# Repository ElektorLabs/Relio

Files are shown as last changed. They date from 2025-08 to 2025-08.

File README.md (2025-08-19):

# Relio
Relio : A Matter-Enabled Smart Controller for AC Appliances 
**Version:** v1  

## 📖 Project Overview

This project is a **Matter-enabled smart controller** built around the ESP32, with support for **relay control, environment sensing, energy monitoring, and occupancy detection**.  
It combines **hardware (KiCAD PCB design)** and **firmware (Arduino/C++ code)** into a single, ready-to-build system.

---

## 📂 Repository Structure

```

├── hardware/      # KiCAD PCB design files (schematics & layout)
└── src/           # Source code (Arduino / ESP-IDF compatible)

````

---

## ⚙️ Features

- **3x On/Off Lights** 💡  
  Controlled through a TCA9554 I²C expander.  
  - Always start **OFF** when powered up (safe startup).  
  - Exposed as **separate Matter endpoints**.  

- **Environmental Sensing (BME688)** 🌡️💧  
  - Temperature & Humidity exposed to Matter.  
  - Pressure & Gas Resistance logged to Serial for debugging.  

- **Energy Monitoring (BL0942)** ⚡  
  - Measures Voltage, Current, Power, Energy, Frequency.  
  - Data shown in Serial logs (Watts/Current can later be exposed to Matter).  

- **Occupancy Detection** 🚶‍♂️  
  - Uses TCA9554 pin 0 as input.  
  - HIGH = Occupied, LOW = Not Occupied.  
  - Reflected in Matter occupancy endpoint.  

- **Commissioning & Control** 🔐  
  - Commission into Matter fabric with QR/Manual code.  
  - BOOT button short press = toggle Light 1.  
  - BOOT button long press (5s) = decommission node.  

---

## 🧑‍💻 How the Code Works

- **Relay Control:**  
  `SWITCH1/2/3` booleans track relay states. Callbacks ensure Matter state and hardware (TCA9554 relays) stay in sync.  

- **BME688:**  
  Reads real temperature/humidity every 5s → updates Matter.  
  Pressure/gas logged for debugging but not exposed to Matter (yet).  

- **BL0942:**  
  Runs on `Serial1` (pins RX=4, TX=5, 4800 baud). Provides live power metrics to Serial monitor.  

- **Occupancy:**  
  Directly read from **TCA9554 pin 0**. When state changes, it’s pushed to the Matter controller and printed to Serial.  

---

## 🚀 Getting Started

1. Clone this repo:  
   ```bash
   git clone https://github.com/ElektorLabs/Relio.git
2. Open the src/ folder in Arduino IDE or PlatformIO.

3. Install dependencies:

   * [Espressif Matter Arduino](https://github.com/espressif/arduino-esp32)
   * [TCA9554 library](https://github.com/RobTillaart/TCA9554)
   * [BL0942 library](https://github.com/santerilindfors/BL0942)
   * [BME688 library](https://github.com/styropyr0/BME688)

4. Upload the code to your ESP32.

5. Use your Matter controller app to commission the device.

## 🛠️ Future Work

* Expose BL0942 **Power/Current** as native Matter attributes.
* Add Matter endpoints for **Pressure** & **Gas Resistance**.
* Add **configurable boot behavior** (restore last state vs always OFF).

---

## ⚠️ Disclaimer

This project is provided **as-is**, without warranty of any kind.
⚡ **Caution:** This project involves **mains-level voltages** (relays, energy metering).
Only experienced users should build or test this hardware. Always follow **electrical safety best practices** when working with AC-powered circuits.

The author is **not responsible** for any damage, injury, or loss caused by misuse of this code or hardware.

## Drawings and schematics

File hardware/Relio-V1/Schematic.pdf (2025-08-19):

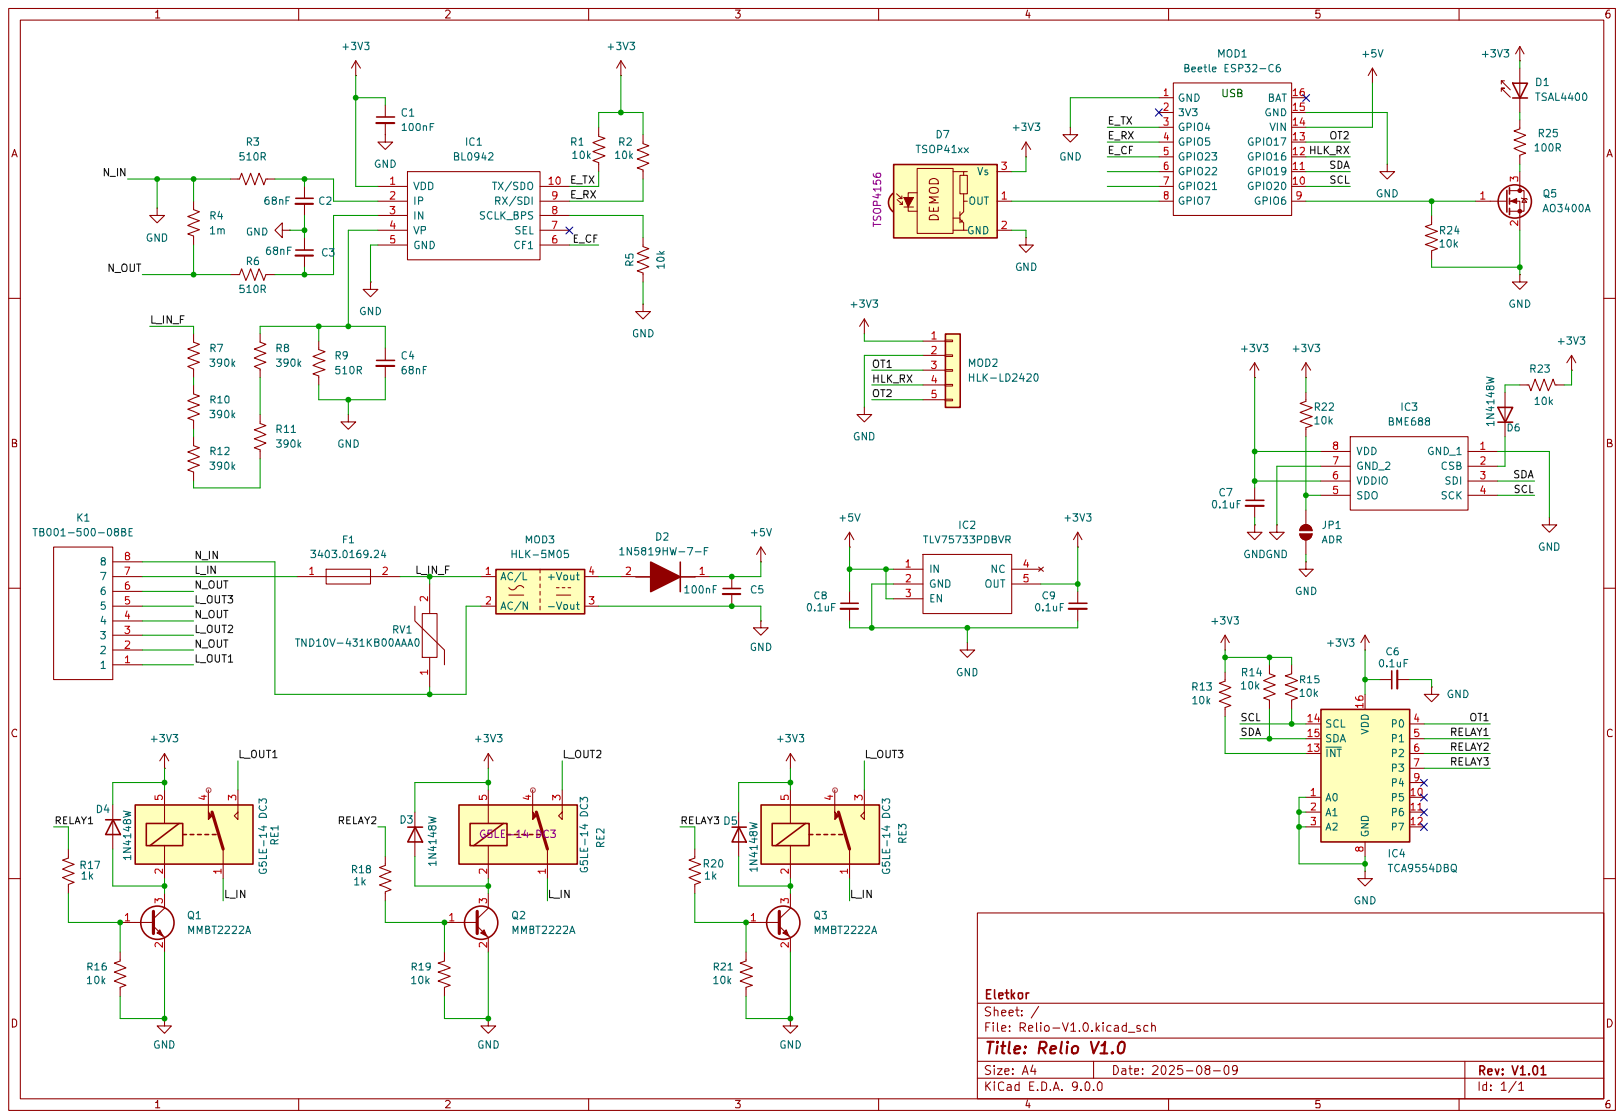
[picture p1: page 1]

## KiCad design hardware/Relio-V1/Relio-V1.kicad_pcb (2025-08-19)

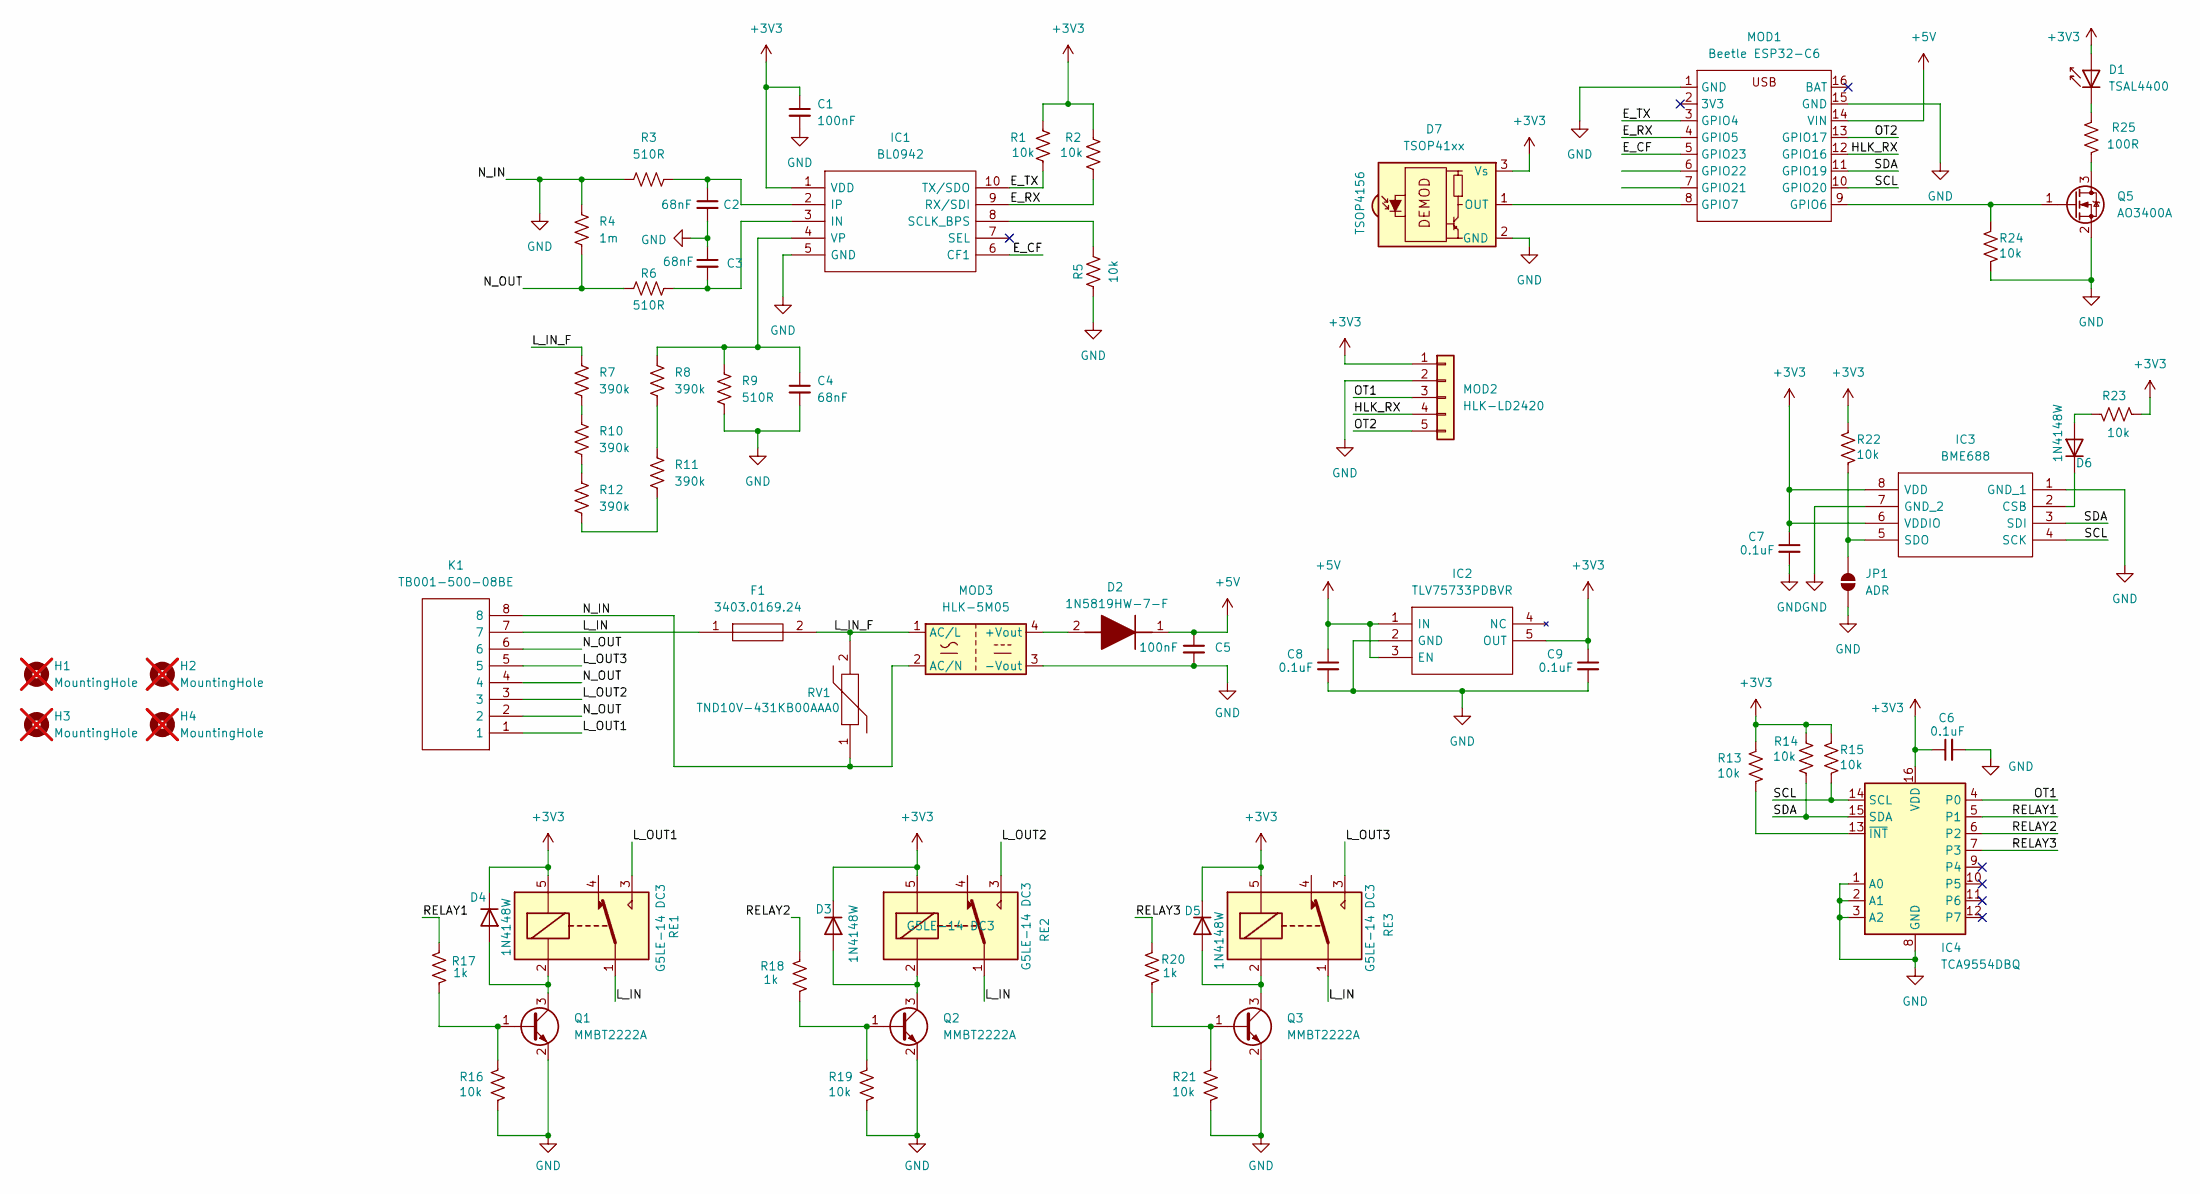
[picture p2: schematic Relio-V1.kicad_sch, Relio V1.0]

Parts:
C1, C5: 100nF; C_0805_2012Metric_Pad1.18x1.45mm_HandSolder; Manufacturer_Part_Number C0805C104M3RAC
C2, C3, C4: 68nF; C_0805_2012Metric_Pad1.18x1.45mm_HandSolder; Manufacturer_Part_Number C0805C683KARACAUTO
C6, C7, C8, C9: 0.1uF; C_0805_2012Metric_Pad1.18x1.45mm_HandSolder; Manufacturer_Part_Number C0805C104M3RAC
D1: TSAL4400; LED_D3.0mm_IRBlack; Manufacturer_Part_Number TSAL4400
D2: 1N5819HW-7-F; SOD3716X145N; Mouser Part Number 621-1N5819HW-F
D3, D4, D5, D6: 1N4148W; D_SOD-123; Manufacturer_Part_Number 1N4148W
D7: TSOP41xx; Vishay_MINICAST-3Pin; Manufacturer_Part_Number TSOP4156
F1: 3403.0169.24; FUSC10130X300N; Mouser Part Number 693-3403.0169.24
H1, H2, H3, H4: MountingHole; MountingHole_3.2mm_M3; not fitted
IC1: BL0942; SOP50P490X110-10N; Manufacturer_Part_Number BL0942
IC2: TLV75733PDBVR; SOT95P280X145-5N; Mouser Part Number 595-TLV75733PDBVR
IC3: BME688; Mouser Part Number 262-BME688
IC4: TCA9554DBQ; SSOP-16_3.9x4.9mm_P0.635mm; Manufacturer_Part_Number TCA9554DBQ
JP1: ADR; SolderJumper-2_P1.3mm_Open_RoundedPad1.0x1.5mm
K1: TB001-500-08BE; TB00150008BE; Mouser Part Number 490-TB001-500-08BE
MOD1: Beetle ESP32-C6; Manufacturer_Part_Number Beetle ESP32-C6
MOD2: HLK-LD2420; PinHeader_1x05_P2.54mm_Vertical; Manufacturer_Part_Number HLK-LD2420
MOD3: HLK-5M05; Converter_ACDC_Hi-Link_HLK-5Mxx; Manufacturer_Part_Number HLK-5M05
Q1, Q2, Q3: MMBT2222A; SOT-23; Manufacturer_Part_Number MMBT2222A
Q5: AO3400A; SOT-23; Manufacturer_Part_Number AO3400A
R1, R2, R5, R13, R14, R15, R16, R19, R21, R22, R23, R24: 10k; R_0805_2012Metric_Pad1.20x1.40mm_HandSolder; Manufacturer_Part_Number 0805W8J0103T5E
R3, R6, R9: 510R; R_0805_2012Metric_Pad1.20x1.40mm_HandSolder; Manufacturer_Part_Number SDR10EZPF5100
R4: 1m; R_1210_3225Metric
R7, R8, R10, R11, R12: 390k; R_2010_5025Metric; Manufacturer_Part_Number CRGCQ2010F390K
R17, R18, R20: 1k; R_0805_2012Metric_Pad1.20x1.40mm_HandSolder; Manufacturer_Part_Number 0805W8J0102T5E
R25: 100R; R_0805_2012Metric_Pad1.20x1.40mm_HandSolder; Manufacturer_Part_Number 0805S8J0101T5E
RE1, RE2, RE3: G5LE-14 DC3; Relay_SPDT_Omron-G5LE-1; Manufacturer_Part_Number G5LE-14 DC3
RV1: TND10V-431KB00AAA0; TND10V431KB00AAA0; Manufacturer_Part_Number TND10V-431KB00AAA0

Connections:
+3V3: C1.1, C6.1, C7.1, C9.1, D1.2 (A), D3.1 (K), D4.1 (K), D5.1 (K), D7.3 (Vs), IC1.1 (VDD), IC2.5 (OUT), IC3.6 (VDDIO), IC3.8 (VDD), IC4.16 (VDD), MOD2.1, R1.1, R2.1, R13.1, R14.1, R15.1, R22.1, R23.1, RE1.5, RE2.5, RE3.5
+5V: C5.1, C8.1, D2.1 (K), IC2.1 (IN), IC2.3 (EN), MOD1.14 (VIN)
/E_CF: IC1.6 (CF1), MOD1.5 (GPIO23)
/E_RX: IC1.9 (RX/SDI), MOD1.4 (GPIO5), R2.2
/E_TX: IC1.10 (TX/SDO), MOD1.3 (GPIO4), R1.2
/HLK_RX: MOD1.12 (GPIO16), MOD2.4
/L_IN: F1.1, K1.7, RE1.1, RE2.1, RE3.1
/L_IN_F: F1.2, MOD3.1 (AC/L), R7.2, RV1.2
/L_OUT1: K1.1, RE1.3
/L_OUT2: K1.3, RE2.3
/L_OUT3: K1.5, RE3.3
/N_OUT: K1.2, K1.4, K1.6, R4.1, R6.1
/OT1: IC4.4 (P0), MOD2.3
/OT2: MOD1.13 (GPIO17), MOD2.5
/RELAY1: IC4.5 (P1), R17.2
/RELAY2: IC4.6 (P2), R18.2
/RELAY3: IC4.7 (P3), R20.2
/SCL: IC3.4 (SCK), IC4.14 (SCL), MOD1.10 (GPIO20), R15.2
/SDA: IC3.3 (SDI), IC4.15 (SDA), MOD1.11 (GPIO19), R14.2
GND: C1.2, C2.2, C3.1, C4.2, C5.2, C6.2, C7.2, C8.2, C9.2, D7.2 (GND), IC1.5 (GND), IC2.2 (GND), IC3.1 (GND_1), IC3.7 (GND_2), IC4.1 (A0), IC4.2 (A1), IC4.3 (A2), IC4.8 (GND), JP1.1 (A), K1.8, MOD1.1 (GND), MOD1.15 (GND), MOD2.2, MOD3.2 (AC/N), MOD3.3 (-Vout), Q1.2 (E), Q2.2 (E), Q3.2 (E), Q5.2 (S), R3.1, R4.2, R5.1, R9.1, R16.2, R19.2, R21.2, R24.2, RV1.1
unnamed: D1.1 (K), R25.1
unnamed: D2.2 (A), MOD3.4 (+Vout)
unnamed: D3.2 (A), Q2.3 (C), RE2.2
unnamed: D4.2 (A), Q1.3 (C), RE1.2
unnamed: D5.2 (A), Q3.3 (C), RE3.2
unnamed: D6.2 (A), R23.2
unnamed: D6.1 (K), IC3.2 (CSB)
unnamed: D7.1 (OUT), MOD1.8 (GPIO7)
unnamed: C3.2, IC1.3 (IN), R6.2
unnamed: C2.1, IC1.2 (IP), R3.2
unnamed: IC1.8 (SCLK_BPS), R5.2
unnamed: C4.1, IC1.4 (VP), R8.2, R9.2
unnamed: IC3.5 (SDO), JP1.2 (B), R22.2
unnamed: IC4.13 (~INT), R13.2
unnamed: MOD1.9 (GPIO6), Q5.1 (G), R24.1
unnamed: Q1.1 (B), R16.1, R17.1
unnamed: Q2.1 (B), R18.1, R19.1
unnamed: Q3.1 (B), R20.1, R21.1
unnamed: Q5.3 (D), R25.2
unnamed: R10.1, R12.1
unnamed: R7.1, R10.2
unnamed: R11.1, R12.2
unnamed: R8.1, R11.2

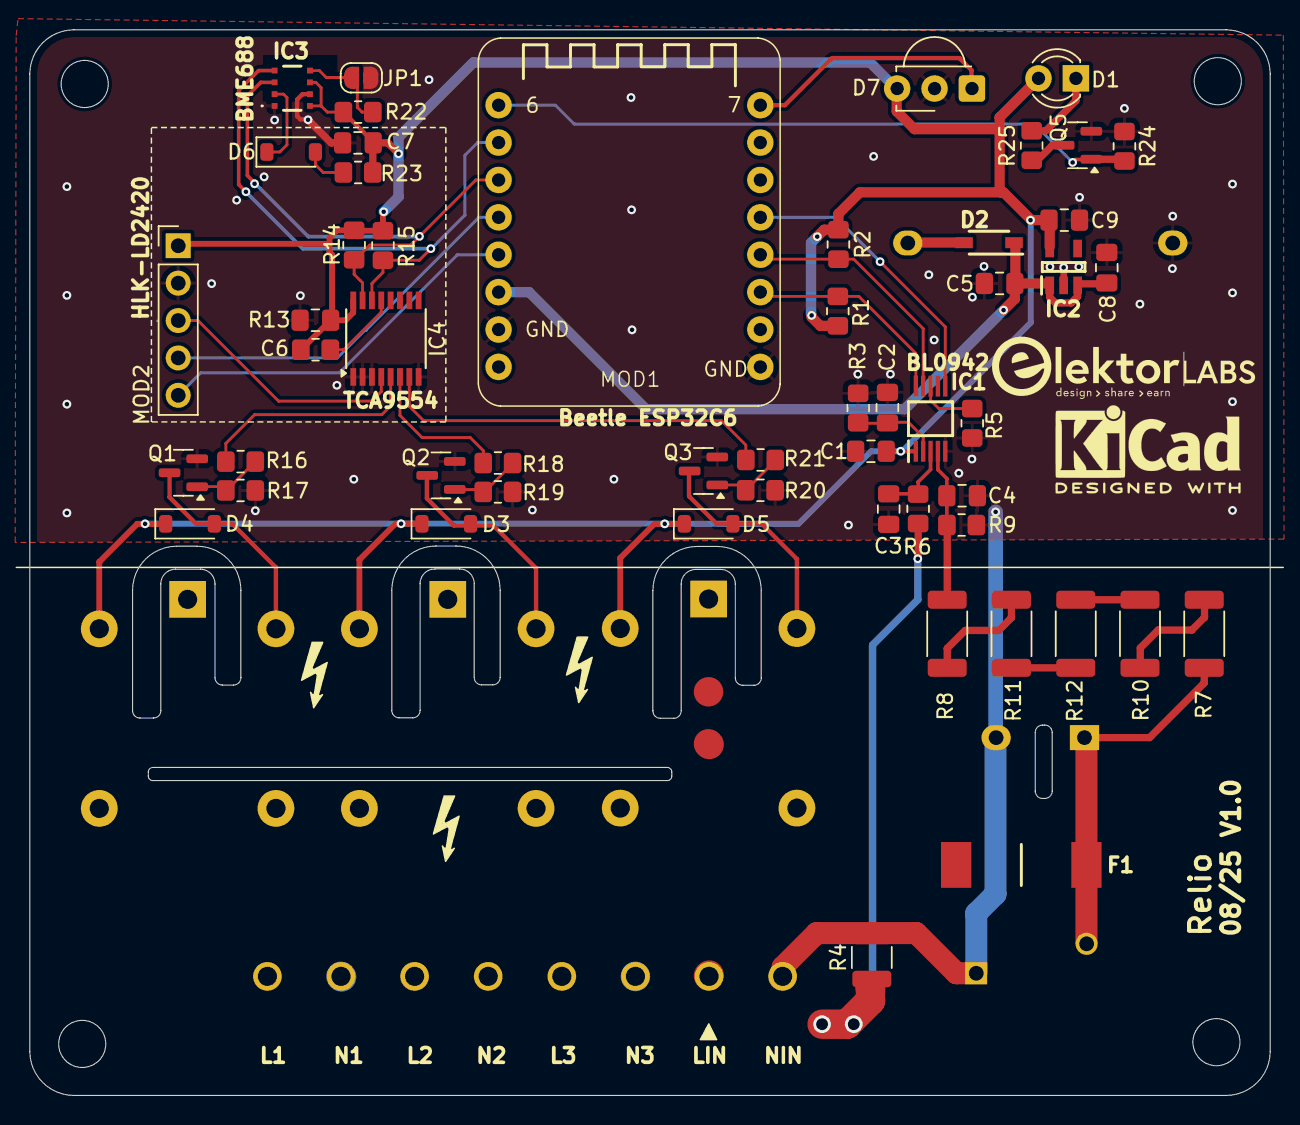
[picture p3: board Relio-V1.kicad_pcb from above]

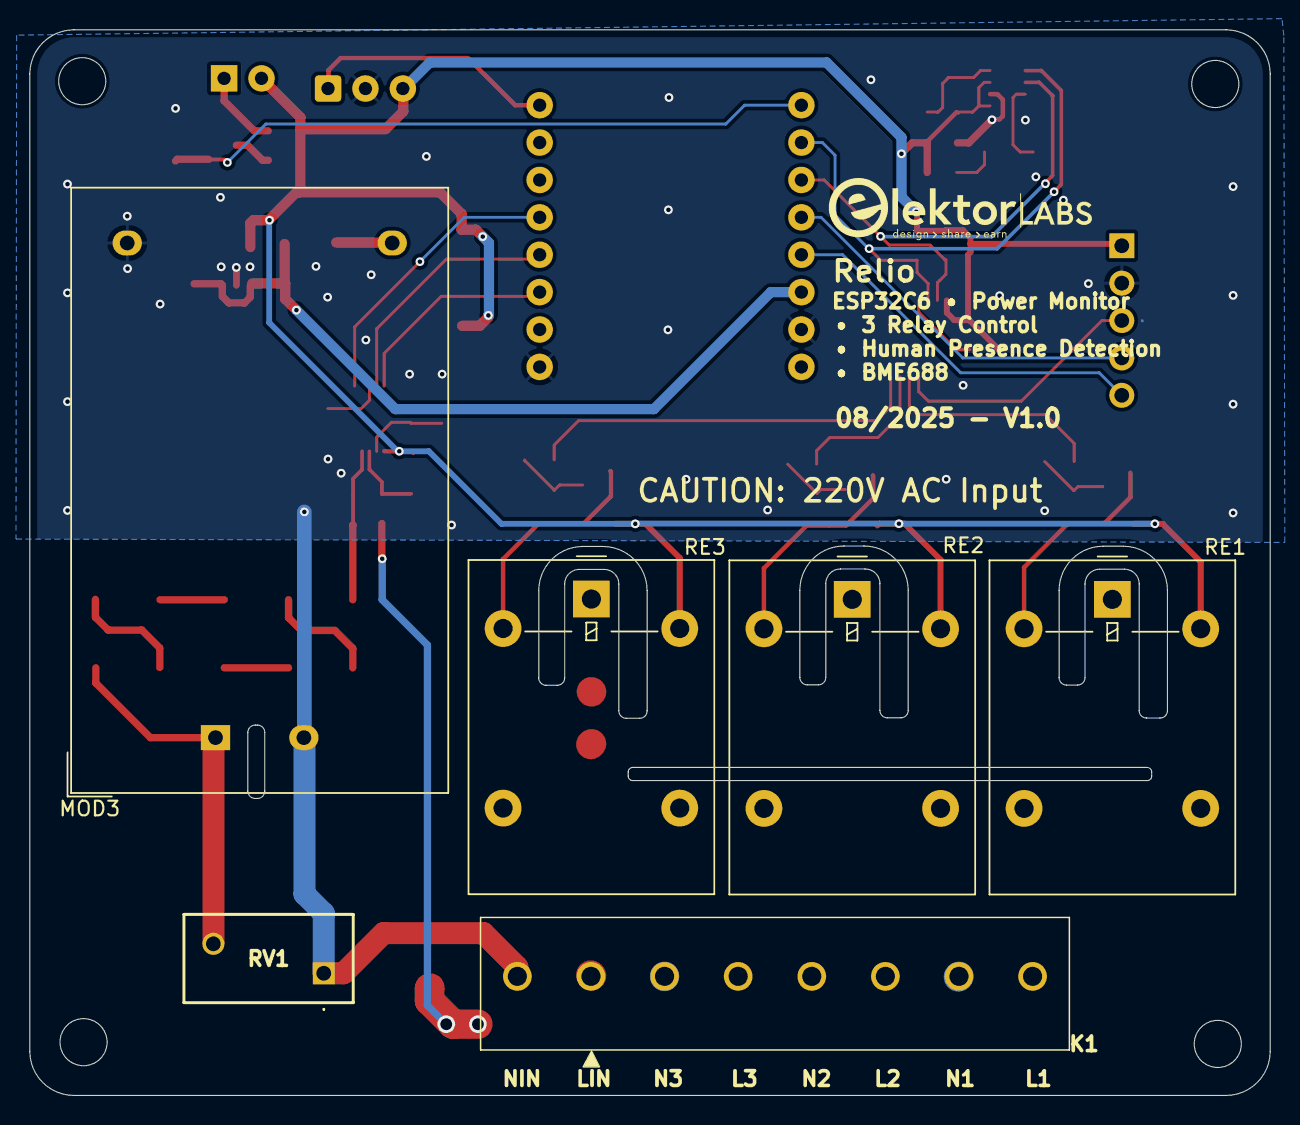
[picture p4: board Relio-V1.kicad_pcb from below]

Board: 2 copper layers, 84.3 x 72.4 mm, 63 parts (6 on the bottom side), 43 nets.

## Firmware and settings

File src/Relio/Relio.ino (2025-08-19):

/*
  Project: Relio : Multi-Endpoint Matter Device with Environmental & Energy Monitoring
  Version: v1
  Author : Saad Imtiaz
  Date   : 16 August 2025

  ---------------------------------------------------------------------------
  Functionality:
  - Implements a Matter node with multiple endpoints:
      • 3x On/Off switches mapped to relays via TCA9554 I²C expander
        → always forced OFF at startup (hardware + Matter state)
      • Temperature & Humidity via BME688 (I²C @ 0x76)
        → real sensor data exposed to Matter, pressure & gas printed to Serial
      • Occupancy sensor controlled by a boolean variable (OCCUPANCY)
      • Energy monitoring via BL0942 (UART on pins RX=4, TX=5)
        → Voltage, Current, Power, Energy, Frequency printed to Serial
  - Supports commissioning / decommissioning into a Matter fabric
    • Short press on BOOT button toggles Light 1
    • Long press (5s) decommissions the node

  ---------------------------------------------------------------------------
  Features Implemented:
  ✔ 3x Relay control with Matter synchronization
  ✔ Safe startup (all relays OFF, state reflected in controller)
  ✔ Real-time Temperature & Humidity from BME688
  ✔ Pressure & Gas resistance (BME688) logged to Serial
  ✔ Occupancy endpoint.
  ✔ BL0942 energy meter integration (Serial monitoring)
  ✔ Commissioning status & QR/manual pairing codes over Serial

  ---------------------------------------------------------------------------
  Features To Be Added (future roadmap):
  - Expose BL0942 power/current data as official Matter endpoint(s)
  - Add optional Matter endpoint for BME688 Pressure & Gas Resistance
  - User-configurable boot policy (restore last state vs always-off)
  - Error handling / fallback if BME688 or BL0942 not detected
    ---------------------------------------------------------------------------
*/

#include <Matter.h>
#if !CONFIG_ENABLE_CHIPOBLE
#include <WiFi.h>
#endif
#include <Preferences.h>
#include <Wire.h>
#include "TCA9554.h"
#include <BME688.h>


// ====== BL0942 Energy Meter ======
#include <BL0942.h>
#define BL0942_RX 4
#define BL0942_TX 5
bl0942::BL0942 blSensor(Serial1);

// === Compile-time option: expose Watts (or Current) in Matter ===
// Set to 1 to enable, and make sure your SDK provides a suitable endpoint.
// Common names you might have in recent Arduino Matter builds include something like
// MatterElectricalMeasurement / MatterPowerMeter / MatterPowerSensor.
//
// If you enable, adjust the include/class/methods in the MARKED SECTION below.
#define EXPOSE_WATTS_IN_MATTER 0   // 0 = Serial only (safe default), 1 = publish to Matter (needs endpoint support)
#define PUBLISH_WATTS           1   // 1 = publish watts, 0 = publish current (amps) if endpoint supports it


// WiFi credentials if not using CHIP over BLE
#if !CONFIG_ENABLE_CHIPOBLE
const char *ssid = "xxx";
const char *password = "xxx";
#endif


// ---------- Matter Endpoints ----------
MatterOnOffLight        OnOffLight1;
MatterOnOffLight        OnOffLight2;
MatterOnOffLight        OnOffLight3;
MatterTemperatureSensor TempSensor;
MatterHumiditySensor    HumSensor;
MatterOccupancySensor   Occupancy;
// ---------- Logical states ----------
bool SWITCH1 = false;
bool SWITCH2 = false;
bool SWITCH3 = false;
bool OCCUPANCY = false;  // set true/false in your app logic

// ---------- Persistence ----------
Preferences matterPref;
static constexpr const char *kNS        = "MatterPrefs";
static constexpr const char *kOnOffKey1 = "OnOff1";
static constexpr const char *kOnOffKey2 = "OnOff2";
static constexpr const char *kOnOffKey3 = "OnOff3";

// ---------- Button / Decommission ----------
const uint8_t buttonPin = BOOT_PIN;
uint32_t button_time_stamp = 0;
bool button_state = false;
const uint32_t debouceTime = 250;              // ms
const uint32_t decommissioningTimeout = 5000;  // ms

// ---------- TCA9554 (I²C expander) ----------
TCA9554 TCA(0x20);                    // change I2C address if needed
const bool RELAY_ACTIVE_HIGH = true;  // set false if your relays are active-LOW

// Map switches to expander pins (0..7)
const uint8_t RELAY1_PIN = 1;
const uint8_t RELAY2_PIN = 2;
const uint8_t RELAY3_PIN = 3;

// ---------- BME688 (Temp/Humidity/Pressure/Gas) ----------
BME688 bme;        // I²C sensor at 0x76

// Store last BL0942 readings & print timing
struct {
  float voltage = NAN;
  float current = NAN;
  float powerW  = NAN;
  float energy  = NAN;
  float freqHz  = NAN;
  uint32_t lastPrintMs = 0;
} em;

void bl0942DataReceived(bl0942::SensorData &data) {
  em.voltage = data.voltage;
  em.current = data.current;
  em.powerW  = data.watt;
  em.energy  = data.energy;
  em.freqHz  = data.frequency;
}

// ---------- Relay helpers ----------
inline uint8_t relayLevelFor(bool on) {
  if (RELAY_ACTIVE_HIGH) return on ? HIGH : LOW;
  else                   return on ? LOW  : HIGH;
}

void driveRelay(uint8_t pin, bool on) {
  if (pin > 7) return;
  TCA.write1(pin, relayLevelFor(on));
}

void applyAllRelaysFromState() {
  driveRelay(RELAY1_PIN, SWITCH1);
  driveRelay(RELAY2_PIN, SWITCH2);
  driveRelay(RELAY3_PIN, SWITCH3);
}

// ---------- Hard "All OFF on Boot" ----------
void forceAllOffOnBoot() {
  // Logical variables
  SWITCH1 = false;
  SWITCH2 = false;
  SWITCH3 = false;

  // Persist OFF so any later reads are consistent (we ignore prefs at boot)
  matterPref.putBool(kOnOffKey1, false);
  matterPref.putBool(kOnOffKey2, false);
  matterPref.putBool(kOnOffKey3, false);

  // Hardware OFF immediately (before Matter starts)
  driveRelay(RELAY1_PIN, false);
  driveRelay(RELAY2_PIN, false);
  driveRelay(RELAY3_PIN, false);
}

// ---------- On/Off callbacks (drive relays + persist) ----------
bool setLight1(bool state) {
  Serial.printf("Light 1 -> %s\r\n", state ? "ON" : "OFF");
  SWITCH1 = state;
  matterPref.putBool(kOnOffKey1, state);
  driveRelay(RELAY1_PIN, state);
  return true;
}
bool setLight2(bool state) {
  Serial.printf("Light 2 -> %s\r\n", state ? "ON" : "OFF");
  SWITCH2 = state;
  matterPref.putBool(kOnOffKey2, state);
  driveRelay(RELAY2_PIN, state);
  return true;
}
bool setLight3(bool state) {
  Serial.printf("Light 3 -> %s\r\n", state ? "ON" : "OFF");
  SWITCH3 = state;
  matterPref.putBool(kOnOffKey3, state);
  driveRelay(RELAY3_PIN, state);
  return true;
}

// ---------- Commissioning helper ----------
static void waitForCommissioningIfNeeded() {
  if (Matter.isDeviceCommissioned()) return;

  Serial.println();
  Serial.println("Matter Node is not commissioned yet.");
  Serial.println("Open your Matter controller to add this device.");
  Serial.printf("Manual pairing code: %s\r\n", Matter.getManualPairingCode().c_str());
  Serial.printf("QR code URL: %s\r\n", Matter.getOnboardingQRCodeUrl().c_str());

  uint32_t tick = 0;
  while (!Matter.isDeviceCommissioned()) {
    delay(100);
    if ((tick++ % 50) == 0) Serial.println("Waiting for commissioning...");
  }
  Serial.println("Commissioned and connected. Ready for use.");
}

void setup() {
  Serial.begin(115200);
  pinMode(buttonPin, INPUT_PULLUP);

#if !CONFIG_ENABLE_CHIPOBLE
  Serial.printf("Connecting to %s\r\n", ssid);
  WiFi.begin(ssid, password);
  while (WiFi.status() != WL_CONNECTED) {
    delay(500);
    Serial.print(".");
  }
  Serial.printf("\r\nWiFi connected. IP: %s\r\n", WiFi.localIP().toString().c_str());
#endif

  // ---- I²C / TCA9554 init ----
  Wire.begin();         // SDA/SCL defaults
  Wire.setClock(50000); // conservative; raise if stable (100k/400k)

  if (!TCA.begin()) {
    Serial.println("TCA9554 not found or init failed!");
  } else {
    Serial.println("TCA9554 initialized.");
  }
  // Configure all pins as outputs and default OFF
  for (int i = 0; i < 8; i++) {
 if (i == 0) {
    TCA.pinMode1(i, INPUT);   // pin 0 reserved for occupancy sensor
  } else {
    TCA.pinMode1(i, OUTPUT);
    TCA.write1(i, relayLevelFor(false));
  }
  }

  // ---- Preferences ----
  matterPref.begin(kNS, false);

  // ---- BME688 init @ 0x76 ----
  if (!bme.begin(0x76)) {
    Serial.println("Failed to initialize BME688 @0x76!");
    // If you want to continue without BME, comment out the next line:
    // while (1) delay(10);
  } else {
    Serial.println("BME688 initialized successfully!");
  }

  // Enforce "all OFF on boot" BEFORE Matter starts
  forceAllOffOnBoot();

  // ---- Matter endpoints (start explicitly OFF) ----
  OnOffLight1.begin(false);
  OnOffLight2.begin(false);
  OnOffLight3.begin(false);
  OnOffLight1.onChange(setLight1);
  OnOffLight2.onChange(setLight2);
  OnOffLight3.onChange(setLight3);

  // Temp/Humidity endpoints (start 0, updated from BME688 in loop)
  TempSensor.begin(0.0f);
  HumSensor.begin(0.0f);

  // Occupancy endpoint (boolean-based)
  Occupancy.begin();
  Occupancy.setOccupancy(OCCUPANCY);

  // ---- Start Matter ----
  Matter.begin();

  // ---- Commissioning ----
  waitForCommissioningIfNeeded();

  // Make sure controllers reflect OFF immediately
  OnOffLight1.setOnOff(false);
  OnOffLight2.setOnOff(false);
  OnOffLight3.setOnOff(false);
  OnOffLight1.updateAccessory();
  OnOffLight2.updateAccessory();
  OnOffLight3.updateAccessory();

  // Ensure hardware matches (already OFF, but keep for symmetry)
  applyAllRelaysFromState();

  // ---- BL0942 serial init ----
  Serial1.begin(4800, SERIAL_8N1, BL0942_RX, BL0942_TX);
  blSensor.setup();                       // default ModeConfig
  blSensor.onDataReceived(bl0942DataReceived);
  Serial.println("BL0942 initialized. Waiting for data...");
}

void loop() {
  // Re-block if decommissioned during runtime
  if (!Matter.isDeviceCommissioned()) {
    waitForCommissioningIfNeeded();
    OnOffLight1.setOnOff(false);
    OnOffLight2.setOnOff(false);
    OnOffLight3.setOnOff(false);
    OnOffLight1.updateAccessory();
    OnOffLight2.updateAccessory();
    OnOffLight3.updateAccessory();
    Occupancy.setOccupancy(OCCUPANCY);
    applyAllRelaysFromState();

  }

  const uint32_t now = millis();

  // ---- BME688 update every 5s ----
  static uint32_t lastBmeMs = 0;
  if (now - lastBmeMs >= 5000) {
    lastBmeMs = now;

    float tempC = bme.readTemperature();
    float humPct = bme.readHumidity();
    float press  = bme.readPressure();
    float gas    = bme.readGas(0);   // IAQ profile 0

    // Print all for debugging
    Serial.printf("BME688  T=%.2f°C  H=%.2f%%  P=%.2f Pa  Gas=%.2f Ω\r\n",
                  tempC, humPct, press, gas);

    // Update Matter endpoints
    if (!isnan(tempC))  TempSensor.setTemperature(tempC);
    if (!isnan(humPct)) HumSensor.setHumidity(humPct);
  }

  // ---- BL0942 processing ----
  blSensor.update();
  blSensor.loop();

  // Print to Serial every ~3s if new data present
  if (now - em.lastPrintMs >= 3000) {
    em.lastPrintMs = now;
    if (!isnan(em.voltage)) {
      Serial.printf("BL0942  V=%.1f V  I=%.3f A  P=%.1f W  E=%.2f Wh  f=%.1f Hz\r\n",
                    em.voltage, em.current, em.powerW, em.energy, em.freqHz);
    } else {
      Serial.println("BL0942  Waiting for data...");
    }
  }

// ---- Occupancy update (from TCA9554 pin 0) ----
static bool lastOccSent = false;
bool occNow = (TCA.read1(0) == HIGH);   // HIGH = occupied, LOW = no one

if (occNow != lastOccSent) {
  lastOccSent = occNow;
  Serial.printf("Occupancy -> %s\r\n", occNow ? "OCCUPIED" : "UN-OCCUPIED");
  Occupancy.setOccupancy(occNow);
}

  // ---- Button handling ----
  if (digitalRead(buttonPin) == LOW && !button_state) {
    button_time_stamp = now;
    button_state = true;
  }
  uint32_t held = now - button_time_stamp;

  // Short press example: toggle Light 1 (optional)
  if (button_state && held > debouceTime && digitalRead(buttonPin) == HIGH) {
    button_state = false;
    Serial.println("Button released: toggling Light 1 (example)...");
    OnOffLight1.toggle();  // updates SWITCH1 via callback, which drives relay 1
  }

  // Long press: decommission node
  if (button_state && held > decommissioningTimeout) {
    Serial.println("Decommissioning the Matter Node...");
    Matter.decommission();
    button_time_stamp = now; // prevent re-trigger
  }
}
